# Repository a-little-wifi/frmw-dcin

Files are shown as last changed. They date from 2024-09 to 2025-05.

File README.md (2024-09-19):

# Framework laptop DC-in module

This is a Framework laptop module designed to let you use Dell or HP laptop power supplies with a Framework laptop (or any other device that takes 20V USB-PD)

The schematic for this board was made by [Arya](https://github.com/CRImier), I tweaked it a bit and did the board layout.  
It requires an Altmode Friend, also made by Arya, to handle all the communication and control.

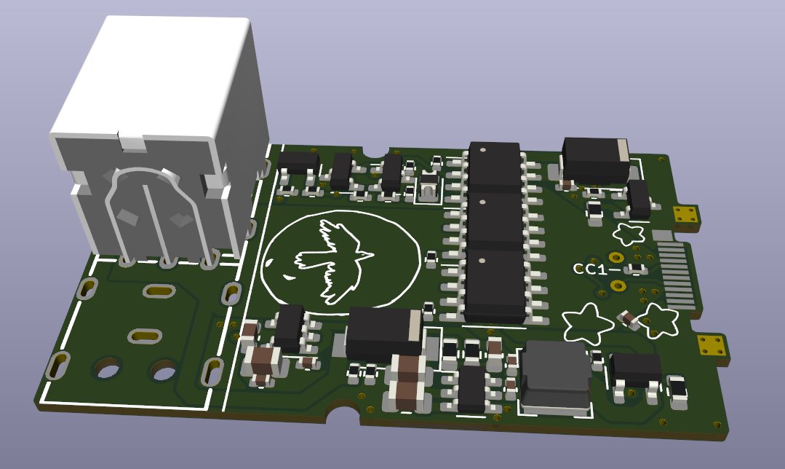
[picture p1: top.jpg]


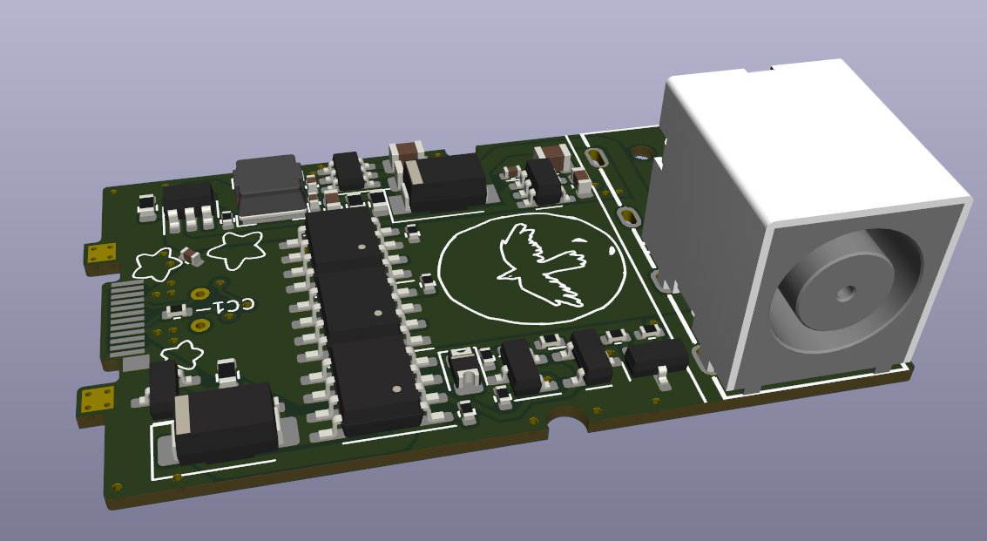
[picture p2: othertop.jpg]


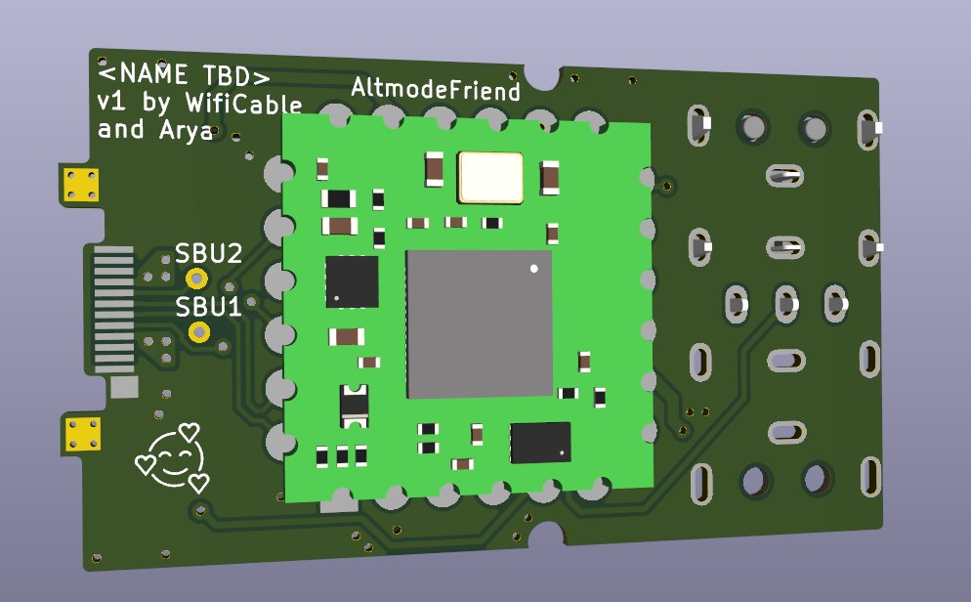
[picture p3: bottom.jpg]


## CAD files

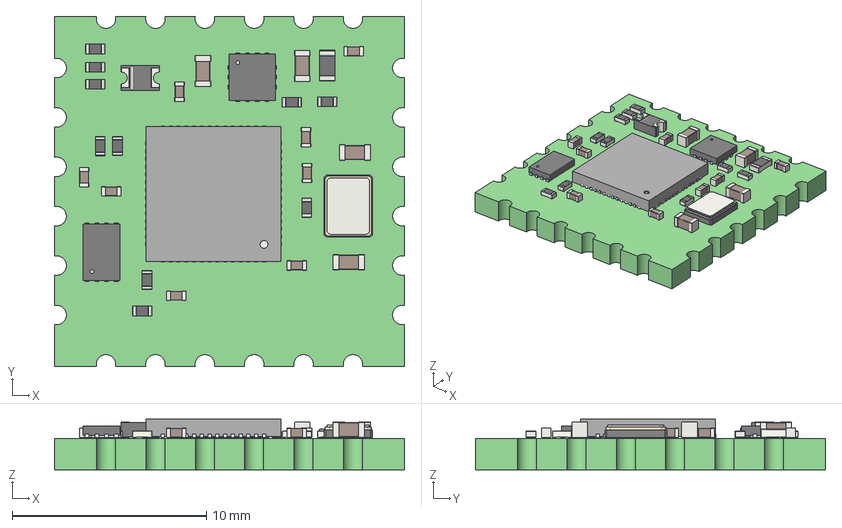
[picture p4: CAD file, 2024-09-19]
frmw_dcin_big/altmode_friend.step
18.0 x 18.0 x 2.60 mm
altmode_friend PCB

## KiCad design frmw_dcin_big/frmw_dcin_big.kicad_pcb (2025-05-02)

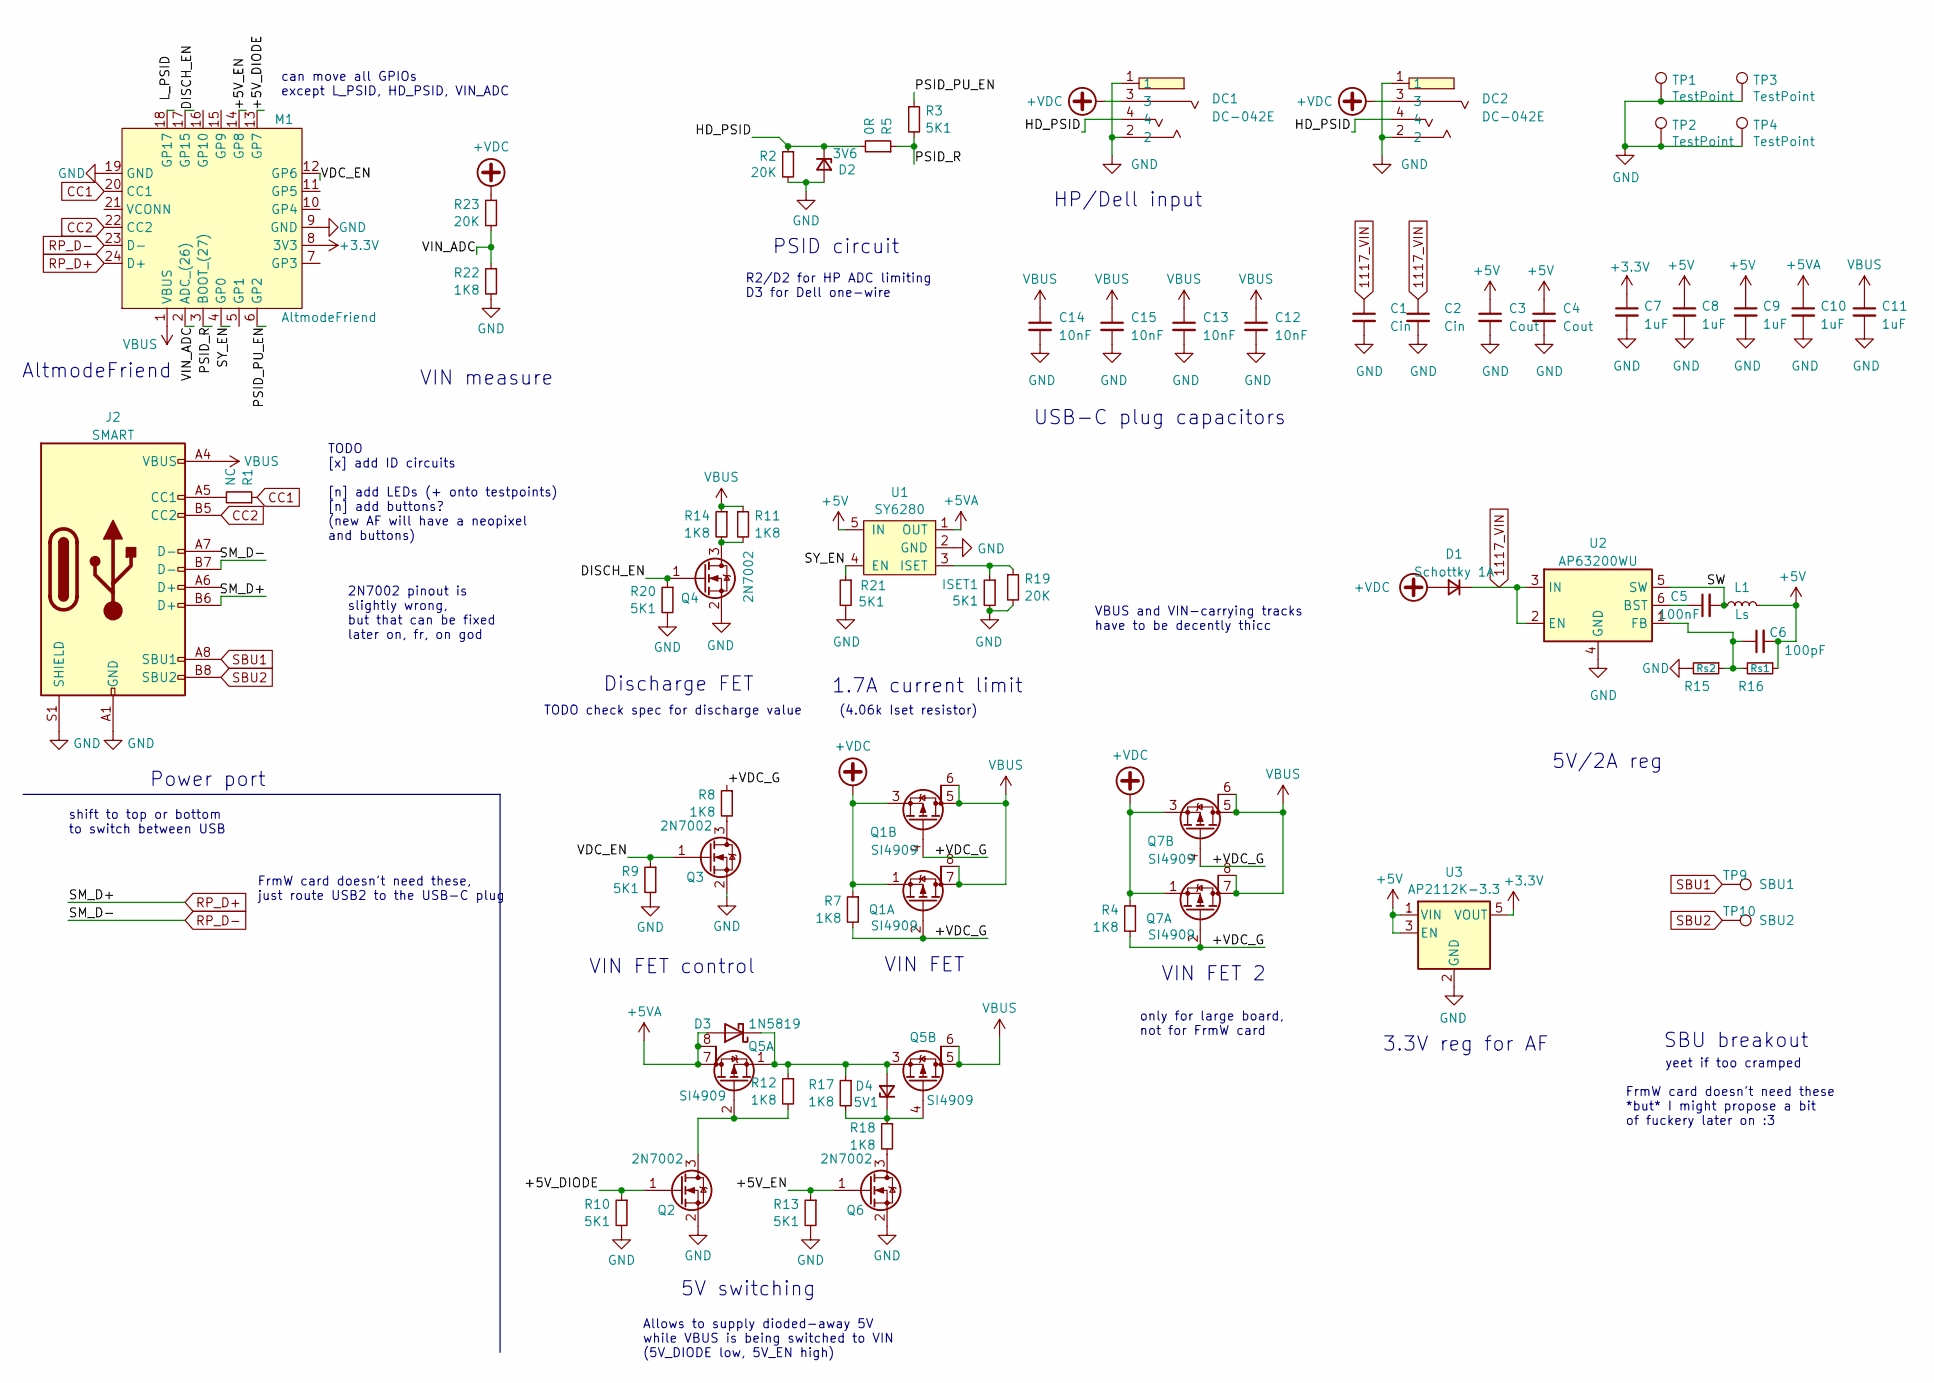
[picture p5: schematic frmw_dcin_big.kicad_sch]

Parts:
C1, C2: Cin; C_0805_2012Metric
C3, C4: Cout; C_0805_2012Metric
C5: 100nF; C_0402_1005Metric
C6: 100pF; C_0603_1608Metric
C7, C8, C9, C10, C11: 1uF; C_0402_1005Metric
C12, C13, C14, C15: 10nF; C_0402_1005Metric
D1: Schottky 1A; D_SMA
D2: 3V6; D_0805_2012Metric
D3: 1N5819; D_SMA
D4: 5V1; D_0805_2012Metric
DC1, DC2: DC-042E; DC-IN-TH_DC-042E; LCSC Part C397340
ISET1: 5K1; R_0402_1005Metric
J2: SMART; USB_C_Plug_Molex_105444
L1: Ls; L_Bourns-SRN4018
M1: AltmodeFriend; altmode_friend
Q1, Q5, Q7: SI4909; SO-8_3.9x4.9mm_P1.27mm
Q2, Q3, Q4, Q6: 2N7002; SOT-23
R1: NC; R_0402_1005Metric
R2, R19, R23: 20K; R_0402_1005Metric
R3, R9, R10, R13, R20, R21: 5K1; R_0402_1005Metric
R4, R7, R8, R11, R12, R14, R17, R18, R22: 1K8; R_0402_1005Metric
R5: 0R; R_0402_1005Metric
R15: Rs2; R_0603_1608Metric
R16: Rs1; R_0603_1608Metric
TP1, TP2, TP3, TP4: TestPoint; TestPoint_Pad_1.5x1.5mm
TP9: SBU1; TestPoint_THTPad_D1.0mm_Drill0.5mm
TP10: SBU2; TestPoint_THTPad_D1.0mm_Drill0.5mm
U1: SY6280; SOT-23-5
U2: AP63200WU; TSOT-23-6
U3: AP2112K-3.3; SOT-23-5

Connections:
1117_VIN: C1.1, C2.1, D1.1 (K), U2.2 (EN), U2.3 (IN)
+3.3V: C7.1, M1.8 (3V3), U3.5 (VOUT)
+5V: C3.1, C4.1, C6.2, C8.1, C9.1, L1.2, R16.1, U1.5 (IN), U3.1 (VIN), U3.3 (EN)
+5VA: C10.1, D3.2 (A), Q5.7 (D), Q5.8 (G), U1.1 (OUT)
+VDC: D1.2 (A), DC1.3, DC2.3, Q1.1 (S), Q1.3 (S), Q7.1 (S), Q7.3 (S), R4.1, R7.1, R23.1
/+5V_DIODE: M1.13 (GP7), Q2.1 (G), R10.1
/+5V_EN: M1.14 (GP8), Q6.1 (G), R13.1
/+VDC_G: Q1.2 (G), Q1.4 (G), Q7.2 (G), Q7.4 (G), R4.2, R7.2, R8.1
/DISCH_EN: M1.17 (GP15), Q4.1 (G), R20.1
/HD_PSID: D2.1 (K), DC1.4, DC2.4, R2.1, R5.2
/PSID_PU_EN: M1.6 (GP2), R3.1
/PSID_R: M1.3 (BOOT_(27)), R3.2, R5.1
/SW: C5.2, L1.1, U2.5 (SW)
/SY_EN: M1.4 (GP0), R21.1, U1.4 (EN)
/VDC_EN: M1.12 (GP6), Q3.1 (G), R9.1
/VIN_ADC: M1.2 (ADC_(26)), R22.1, R23.2
CC1: M1.20 (CC1), R1.1
CC2: J2.B5 (CC2), M1.22 (CC2)
GND: C1.2, C2.2, C3.2, C4.2, C7.2, C8.2, C9.2, C10.2, C11.2, C12.2, C13.2, C14.2, C15.2, D2.2 (A), DC1.1, DC1.2, DC2.1, DC2.2, J2.A1 (GND), J2.A12 (GND), J2.B1 (GND), J2.B12 (GND), J2.S1 (SHIELD), M1.9 (GND), M1.19 (GND), Q2.2 (S), Q3.2 (S), Q4.2 (S), Q6.2 (S), R2.2, R9.2, R10.2, R13.2, R15.2, R19.2, R20.2, R21.2, R22.2, TP1.1, TP2.1, TP3.1, TP4.1, U1.2 (GND), U2.4 (GND), U3.2 (GND); also elsewhere on the board
unnamed: D3.1 (K), D4.2 (A), Q5.1 (S), Q5.3 (S), R12.1, R17.1
unnamed: D4.1 (K), Q5.4 (G), R17.2, R18.1
unnamed: J2.A5 (CC1), R1.2
unnamed: Q2.3 (D), Q5.2 (G), R12.2
unnamed: Q3.3 (D), R8.2
unnamed: Q4.3 (D), R11.2, R14.2
unnamed: Q6.3 (D), R18.2
unnamed 26: R19.1, U1.3 (ISET); also elsewhere on the board
unnamed: C5.1, U2.6 (BST)
unnamed: C6.1, R15.1, R16.2, U2.1 (FB)
RP_D+: J2.B6 (D+), M1.24 (D+)
RP_D-: J2.B7 (D-), M1.23 (D-)
SBU1: J2.A8 (SBU1), TP9.1
SBU2: J2.B8 (SBU2), TP10.1
VBUS: C11.1, C12.1, C13.1, C14.1, C15.1, J2.A4 (VBUS), J2.A9 (VBUS), J2.B4 (VBUS), J2.B9 (VBUS), M1.1 (VBUS), Q1.5 (D), Q1.6 (G), Q1.7 (D), Q1.8 (G), Q5.5 (D), Q5.6 (G), Q7.5 (D), Q7.6 (G), Q7.7 (D), Q7.8 (G), R11.1, R14.1

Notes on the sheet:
HP/Dell input
FrmW card doesn't need these *but* I might propose a bit of fuckery later on :3
PSID circuit
3.3V reg for AF
VIN FET control
USB-C plug capacitors
Allows to supply dioded-away 5V while VBUS is being switched to VIN (5V_DIODE low, 5V_EN high)
VIN FET
TODO check spec for discharge value
only for large board, not for FrmW card
can move all GPIOs except L_PSID, HD_PSID, VIN_ADC
shift to top or bottom to switch between USB
5V/2A reg
VBUS and VIN-carrying tracks have to be decently thicc
Power port
AltmodeFriend
VIN FET 2
TODO [x] add ID circuits [n] add LEDs (+ onto testpoints) [n] add buttons? (new AF will have a neopixel and buttons)
(4.06k Iset resistor)
SBU breakout
FrmW card doesn't need these, just route USB2 to the USB-C plug
VIN measure
R2/D2 for HP ADC limiting D3 for Dell one-wire
yeet if too cramped
2N7002 pinout is slightly wrong, but that can be fixed later on, fr, on god
5V switching
1.7A current limit
Discharge FET

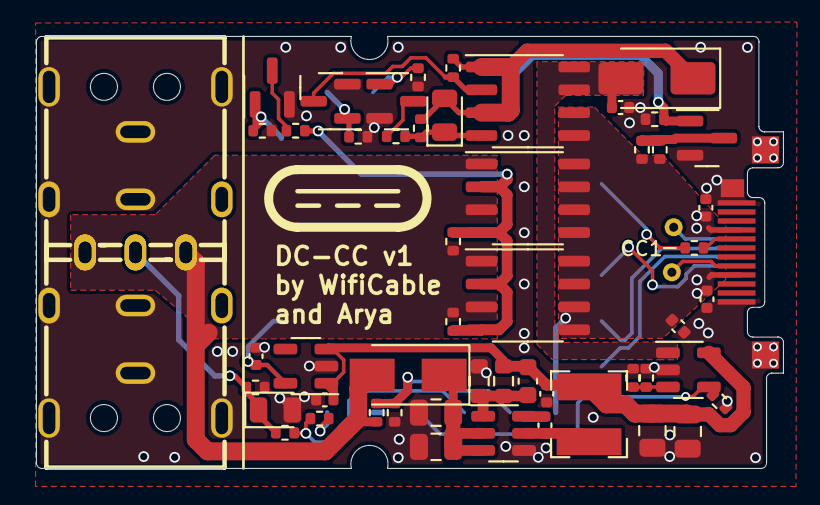
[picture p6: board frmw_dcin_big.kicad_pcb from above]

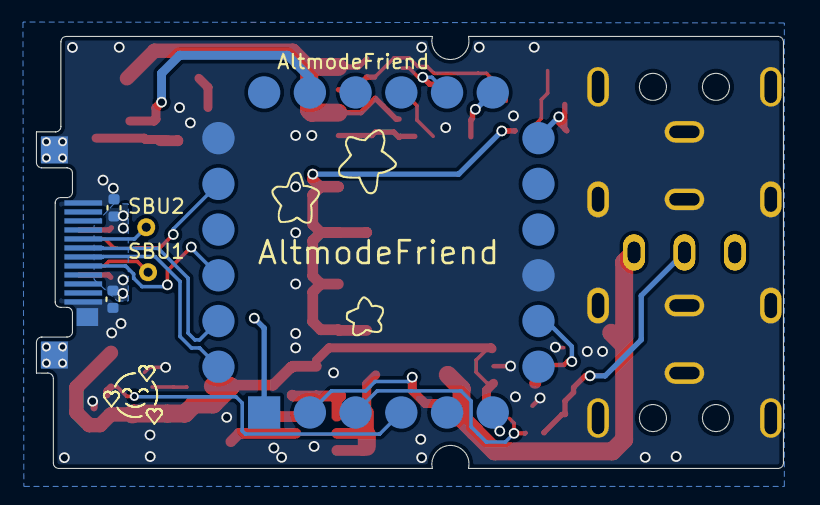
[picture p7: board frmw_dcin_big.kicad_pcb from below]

Board: 4 copper layers, 41.5 x 24.0 mm, 63 parts (5 on the bottom side), 34 nets.

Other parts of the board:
R6: 5K1; R_0402_1005Metric

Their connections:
GND: R6.2; also elsewhere on the board
unnamed 26: R6.1; also elsewhere on the board

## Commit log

2024-09-19 Added project files
    [altmode_friend.step, frmw_dcin_big.kicad_pcb, frmw_dcin_big.kicad_sch]
2025-05-02 design: reviewed. added a proper circuit for HP/Dell center pin detection, did BOM optimizations, recalculated SY6280 resistors, yote via-in-pad, improved tracks and fills, updated USB-C footprint
    [frmw_dcin_big.kicad_pcb, frmw_dcin_big.kicad_sch]
2025-05-02 Added name and logo
    [frmw_dcin_big.kicad_pcb]
2025-05-02 adjusted logo
    [frmw_dcin_big.kicad_pcb]
2025-05-02 Changed to 4 layers
    [frmw_dcin_big.kicad_pcb]
